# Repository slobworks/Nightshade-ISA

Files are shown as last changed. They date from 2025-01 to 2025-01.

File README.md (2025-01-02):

NIGHTSHADE v0.8c2 - Public Domain Cirrus Logic CL-GD542x Based ISA VGA Card

As it says on the package. This card supports a maximum memory size of 1MB or 2MB, depending on the chip you use, using traditional multiple-CAS FPM 256Kx16 SOJ memory. 70ns or faster is recommended.
Created using KiCAD 8.0.
front
back
Features:
- Four layer PCB with generous stitching vias for maximum possible signal integrity
- Optional dedicated regulator for analog DAC power for further improved picture quality
- Supports 1MB of memory with CL-GD5424, or 2MB with CL-GD5426/5428/5429
- Compatible with the N-well variants of the CL-GD542x, including the CL-GD5424, GD5426, GD5428 and GD5429
- Uses 29C010-compatible flash memory for reduced cost; has options to select one of four 32K banks within the large 128K flash memory if you wish to try multiple video BIOSes
- Features my own hand-drawn artwork on back of board

Release History:
- 0.8a: Fixed VESA Feature Connector pinout, now conforms to Cirrus datasheet
- 0.8b: Resolved a number of issues related to VGA output quality (no more wavy interference onscreen!), and reduced the parts count a bit. Fewer parts means less $$ spent, and less breathing of solder fumes.
- 0.8b2: Changed LM334SM to the _much_ cheaper LM334M.
- 0.8c: Pretty heavy tweak-up of both layout, ground pours, and placement of 75 ohm termination resistors following feedback from TmEE, Jorge and others. Thanks everyone who spoke up to help.
Also re-added DPAK LF50 regulator for the RAMDAC, and yes, it is optional if you want to pinch pennies on the dollar - just remember to only populate R22 if you're **not** using a regulator. If you're installing the regulator, leave R22 **OPEN**.
- 0.8c1: Changed ROM footprint to an SMD PLCC-32 socket, and had to re-space stuff around it to make it fit. This looks like it ought to work: https://www.digikey.com/en/products/detail/amphenol-cs-fci/69802-132LF/2023294
- 0.8c2: Moved the LDO and related junk to the front of the board to help minimize the potential for damage. Hopefully things don't get too hot, where it is.

Other people's stuff I've used:
- PLCC-32 footprint from KiCAD (SchrodingersGat ?): https://github.com/KiCad/Housings_LCC.pretty/blob/master/PLCC-32_SMD-Socket.kicad_mod

Released into the Public Domain. Use whatever license floats your boat on your own edits.

As you can see I'm a bit of a neophyte when it comes to this GitHub stuff.
Expect this to change as I become more familiar with the platform.

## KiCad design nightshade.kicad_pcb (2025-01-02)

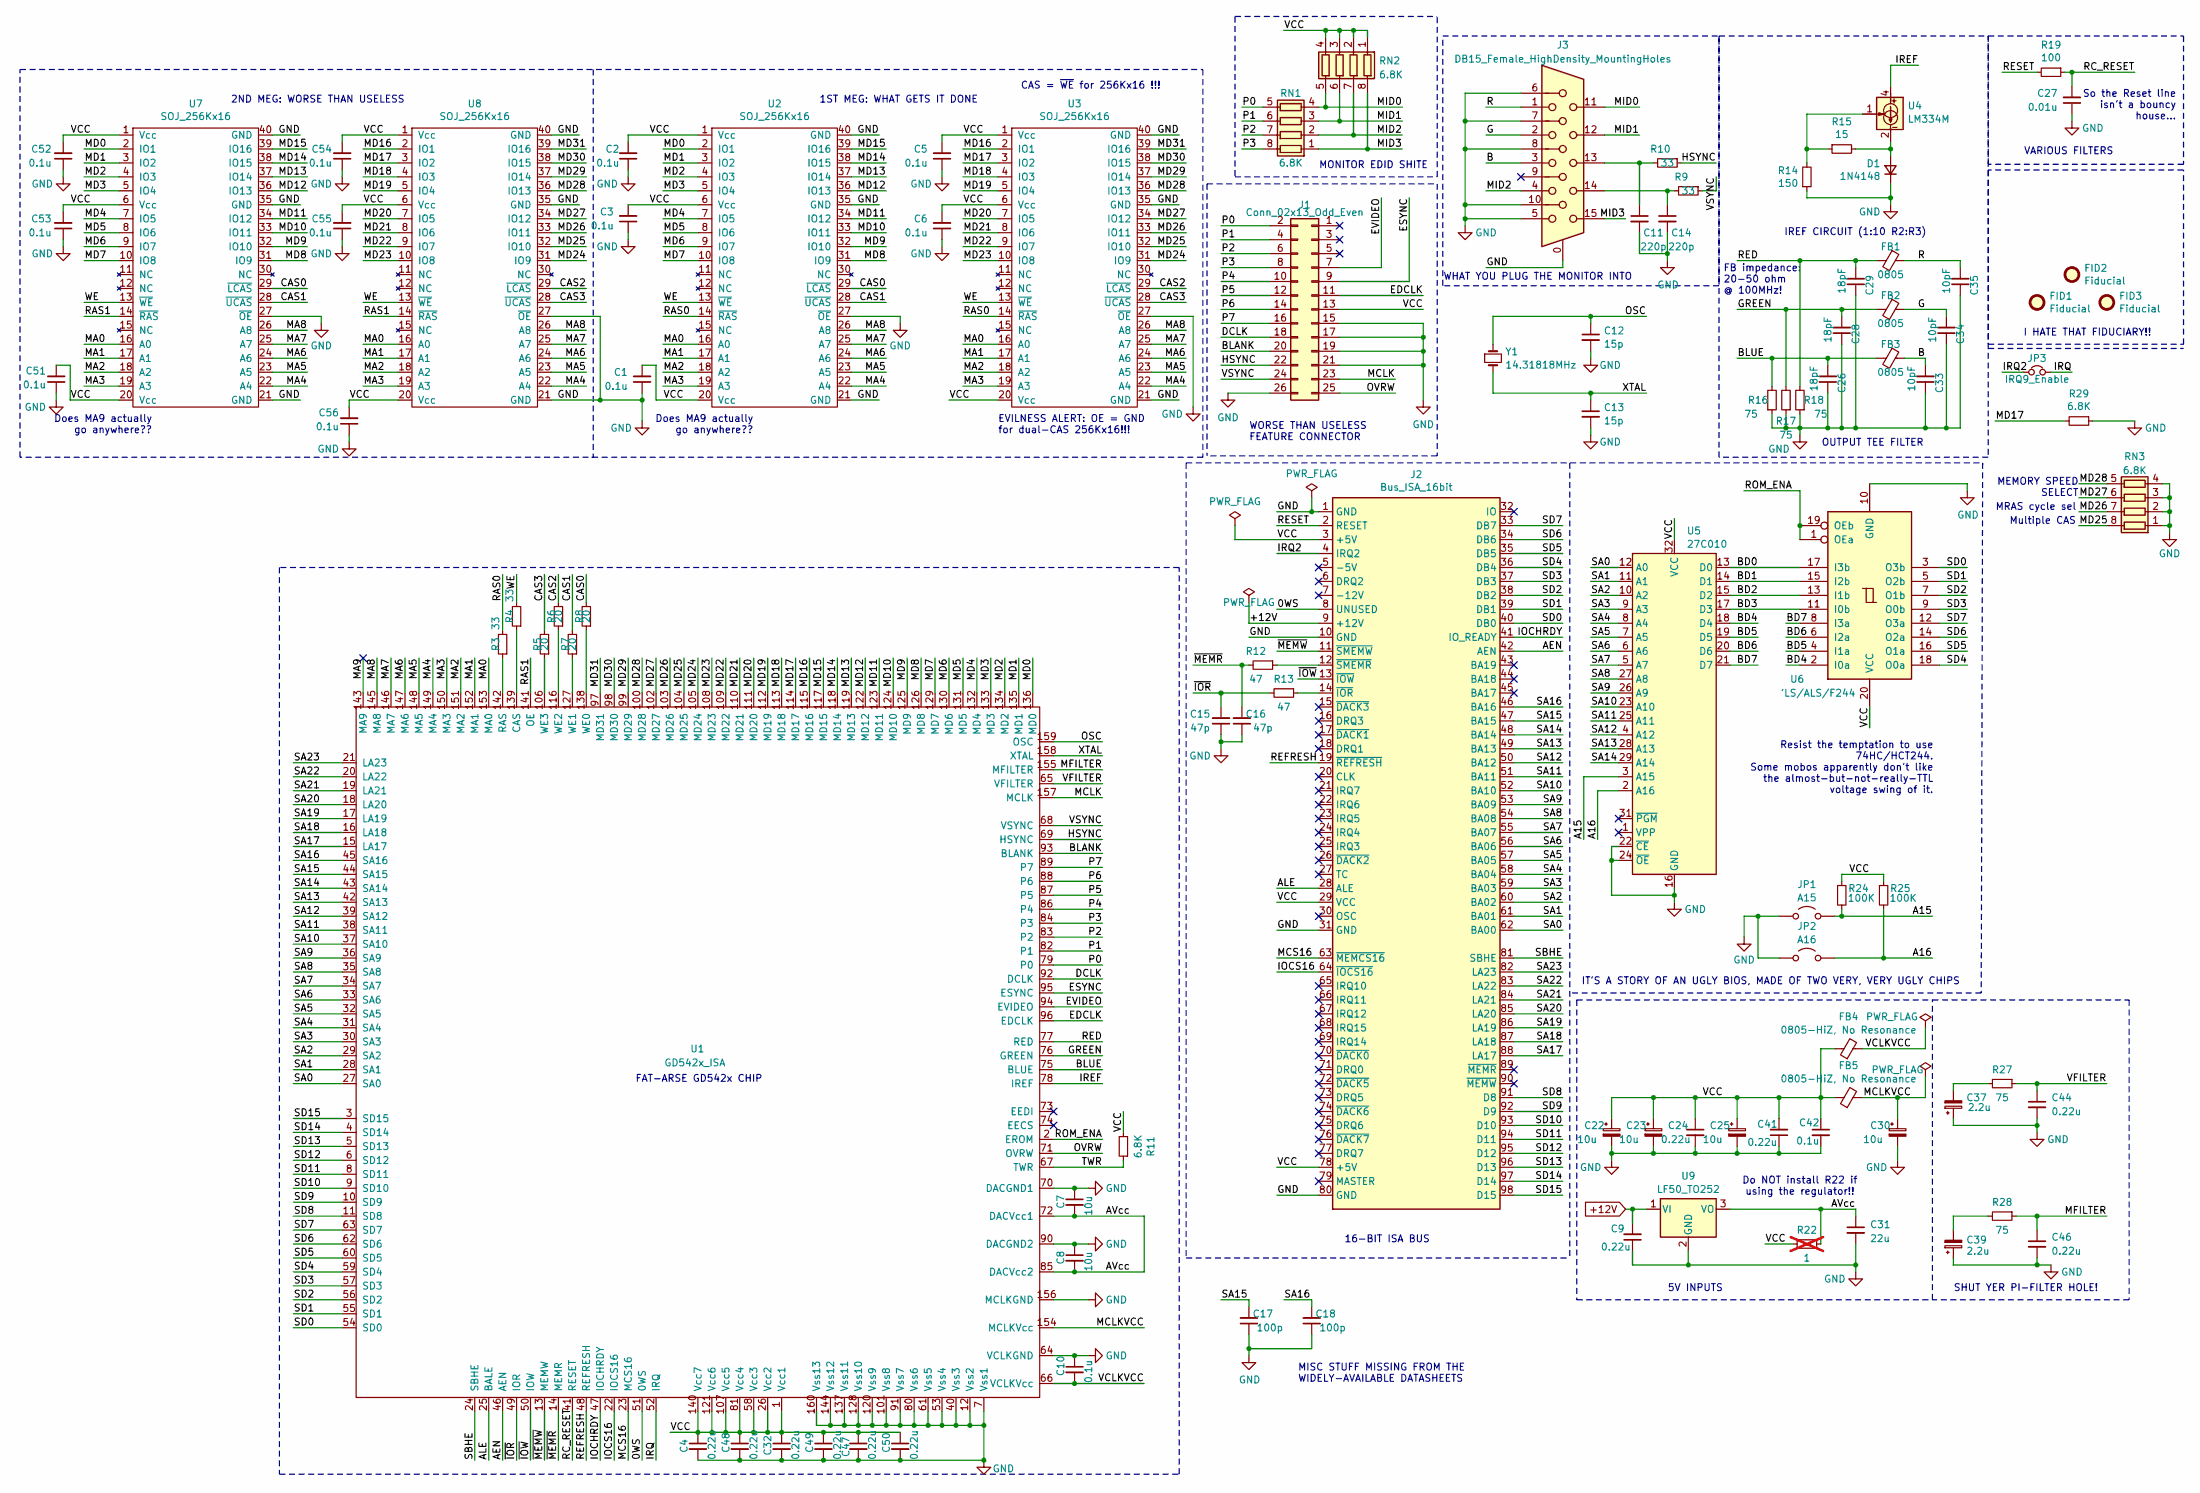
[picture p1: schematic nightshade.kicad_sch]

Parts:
C1, C2, C3, C5, C6, C10, C42, C51, C52, C53, C54, C55, C56: 0.1u; C_0805_2012Metric
C4, C9, C24, C32, C41, C44, C46, C47, C48, C49, C50: 0.22u; C_0805_2012Metric
C7, C8, C22, C23, C25, C30: 10u; C_1206_3216Metric
C11, C14: 220p; C_0805_2012Metric
C12, C13: 15p; C_0805_2012Metric
C15, C16: 47p; C_0805_2012Metric
C17, C18: 100p; C_0805_2012Metric
C26, C28, C29: 18pF; C_0805_2012Metric
C27: 0.01u; C_0805_2012Metric
C31: 22u; C_Elec_4x5.8
C33, C34, C35: 10pF; C_0805_2012Metric
C37, C39: 2.2u; C_0805_2012Metric
D1: 1N4148; D_SOD-323_HandSoldering
FB1, FB2, FB3: 0805; L_0805_2012Metric
FB4, FB5: 0805-HiZ, No Resonance; L_0805_2012Metric
FID1, FID2, FID3: Fiducial; Fiducial_1mm_Mask2mm
J1: Conn_02x13_Odd_Even; PinHeader_2x13_P2.54mm_Vertical
J2: Bus_ISA_16bit; BUS_AT
J3: DB15_Female_HighDensity_MountingHoles; DSUB-15-HD
JP1: A15; PinHeader_1x02_P1.27mm_Vertical
JP2: A16; PinHeader_1x02_P1.27mm_Vertical
JP3: IRQ9_Enable; PinHeader_1x02_P2.54mm_Vertical
R3, R4, R9, R10: 33; R_0805_2012Metric
R5, R6, R7, R8: 20; R_0805_2012Metric
R11: 6.8K; R_0603_1608Metric
R12, R13: 47; R_0805_2012Metric
R14: 150; R_0805_2012Metric
R15: 15; R_0805_2012Metric
R16, R17, R18, R27, R28: 75; R_0805_2012Metric
R19: 100; R_0805_2012Metric
R22: 1; R_0805_2012Metric; not fitted
R24, R25: 100K; R_0603_1608Metric
R29: 6.8K; R_0805_2012Metric
RN1, RN2, RN3: 6.8K; R_Array_Convex_4x0603
U1: GD542x_ISA; PQFP-160_28x28mm_P0.65mm
U2, U3, U7, U8: SOJ_256Kx16; SOJ-40_10.16x26.44mm_P1.27mm
U4: LM334M; SOIC-8_3.9x4.9mm_P1.27mm
U5: 27C010; PLCC-32_SMD-Socket
U6: 'LS/ALS/F244; SOIC-20W_7.5x12.8mm_P1.27mm
U9: LF50_TO252; TO-252-2
Y1: 14.31818MHz; Crystal_SMD_5032-2Pin_5.0x3.2mm_HandSoldering

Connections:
+12V: C9.2, J2.9 (+12V), U9.1 (VI)
/0WS: J2.8 (UNUSED), U1.51 (0WS)
/A15: JP1.2 (B), R24.2, U5.3 (A15)
/A16: JP2.2 (B), R25.2, U5.2 (A16)
/AEN: J2.42 (AEN), U1.46 (AEN)
/ALE: J2.28 (ALE), U1.25 (BALE)
/AVcc: C7.2, C8.2, C31.1, R22.1, U1.72 (DACVcc1), U1.85 (DACVcc2), U9.3 (VO)
/B: C33.2, FB3.1, J3.3
/BD0: U5.13 (D0), U6.17 (I3b)
/BD1: U5.14 (D1), U6.15 (I2b)
/BD2: U5.15 (D2), U6.13 (I1b)
/BD3: U5.17 (D3), U6.11 (I0b)
/BD4: U5.18 (D4), U6.2 (I0a)
/BD5: U5.19 (D5), U6.4 (I1a)
/BD6: U5.20 (D6), U6.6 (I2a)
/BD7: U5.21 (D7), U6.8 (I3a)
/BLANK: J1.20, U1.93 (BLANK)
/BLUE: C26.2, FB3.2, R16.2, U1.75 (BLUE)
/CAS0: R8.2, U2.29 (~LCAS), U7.29 (~LCAS)
/CAS1: R7.2, U2.28 (~UCAS), U7.28 (~UCAS)
/CAS2: R6.2, U3.29 (~LCAS), U8.29 (~LCAS)
/CAS3: R5.2, U3.28 (~UCAS), U8.28 (~UCAS)
/DCLK: J1.18, U1.92 (DCLK)
/EDCLK: J1.11, U1.96 (EDCLK)
/ESYNC: J1.9, U1.95 (ESYNC)
/EVIDEO: J1.7, U1.94 (EVIDEO)
/G: C34.2, FB2.1, J3.2
/GREEN: C28.2, FB2.2, R17.2, U1.76 (GREEN)
/HSYNC: J1.22, R10.1, U1.69 (HSYNC)
/IOCHRDY: J2.41 (IO_READY), U1.47 (IOCHRDY)
/IOCS16: J2.64 (~IOCS16), U1.22 (IOCS16)
/IREF: U1.78 (IREF), U4.4
/IRQ: JP3.2, U1.52 (IRQ)
/IRQ2: J2.4 (IRQ2), JP3.1
/MA0: U1.153 (MA0), U2.16 (A0), U3.16 (A0), U7.16 (A0), U8.16 (A0)
/MA1: U1.152 (MA1), U2.17 (A1), U3.17 (A1), U7.17 (A1), U8.17 (A1)
/MA2: U1.151 (MA2), U2.18 (A2), U3.18 (A2), U7.18 (A2), U8.18 (A2)
/MA3: U1.150 (MA3), U2.19 (A3), U3.19 (A3), U7.19 (A3), U8.19 (A3)
/MA4: U1.149 (MA4), U2.22 (A4), U3.22 (A4), U7.22 (A4), U8.22 (A4)
/MA5: U1.148 (MA5), U2.23 (A5), U3.23 (A5), U7.23 (A5), U8.23 (A5)
/MA6: U1.147 (MA6), U2.24 (A6), U3.24 (A6), U7.24 (A6), U8.24 (A6)
/MA7: U1.146 (MA7), U2.25 (A7), U3.25 (A7), U7.25 (A7), U8.25 (A7)
/MA8: U1.145 (MA8), U2.26 (A8), U3.26 (A8), U7.26 (A8), U8.26 (A8)
/MA9: U1.143 (MA9)
/MCLK: J1.23, U1.157 (MCLK)
/MCLKVCC: C30.1, FB5.2, U1.154 (MCLKVcc)
/MCS16: J2.63 (~MEMCS16), U1.23 (MCS16)
/MD0: U1.136 (MD0), U2.2 (IO1), U7.2 (IO1)
/MD1: U1.135 (MD1), U2.3 (IO2), U7.3 (IO2)
/MD2: U1.134 (MD2), U2.4 (IO3), U7.4 (IO3)
/MD3: U1.133 (MD3), U2.5 (IO4), U7.5 (IO4)
/MD4: U1.132 (MD4), U2.7 (IO5), U7.7 (IO5)
/MD5: U1.131 (MD5), U2.8 (IO6), U7.8 (IO6)
/MD6: U1.130 (MD6), U2.9 (IO7), U7.9 (IO7)
/MD7: U1.129 (MD7), U2.10 (IO8), U7.10 (IO8)
/MD8: U1.126 (MD8), U2.31 (IO9), U7.31 (IO9)
/MD9: U1.125 (MD9), U2.32 (IO10), U7.32 (IO10)
/MD10: U1.124 (MD10), U2.33 (IO11), U7.33 (IO11)
/MD11: U1.123 (MD11), U2.34 (IO12), U7.34 (IO12)
/MD12: U1.122 (MD12), U2.36 (IO13), U7.36 (IO13)
/MD13: U1.119 (MD13), U2.37 (IO14), U7.37 (IO14)
/MD14: U1.118 (MD14), U2.38 (IO15), U7.38 (IO15)
/MD15: U1.117 (MD15), U2.39 (IO16), U7.39 (IO16)
/MD16: U1.115 (MD16), U3.2 (IO1), U8.2 (IO1)
/MD17: R29.2, U1.114 (MD17), U3.3 (IO2), U8.3 (IO2)
/MD18: U1.113 (MD18), U3.4 (IO3), U8.4 (IO3)
/MD19: U1.112 (MD19), U3.5 (IO4), U8.5 (IO4)
/MD20: U1.111 (MD20), U3.7 (IO5), U8.7 (IO5)
/MD21: U1.110 (MD21), U3.8 (IO6), U8.8 (IO6)
/MD22: U1.109 (MD22), U3.9 (IO7), U8.9 (IO7)
/MD23: U1.108 (MD23), U3.10 (IO8), U8.10 (IO8)
/MD24: U1.105 (MD24), U3.31 (IO9), U8.31 (IO9)
/MD25: RN3.8 (R1.2), U1.104 (MD25), U3.32 (IO10), U8.32 (IO10)
/MD26: RN3.7 (R2.2), U1.103 (MD26), U3.33 (IO11), U8.33 (IO11)
/MD27: RN3.6 (R3.2), U1.102 (MD27), U3.34 (IO12), U8.34 (IO12)
/MD28: RN3.5 (R4.2), U1.100 (MD28), U3.36 (IO13), U8.36 (IO13)
/MD29: U1.99 (MD29), U3.37 (IO14), U8.37 (IO14)
/MD30: U1.98 (MD30), U3.38 (IO15), U8.38 (IO15)
/MD31: U1.97 (MD31), U3.39 (IO16), U8.39 (IO16)
/MFILTER: C46.1, R28.1, U1.155 (MFILTER)
/MID0: J3.11, RN1.4 (R4.1), RN2.5 (R4.2)
/MID1: J3.12, RN1.3 (R3.1), RN2.6 (R3.2)
/MID2: J3.4, RN1.2 (R2.1), RN2.7 (R2.2)
/MID3: J3.15, RN1.1 (R1.1), RN2.8 (R1.2)
/OSC: C12.1, U1.159 (OSC), Y1.1
/OVRW: J1.25, U1.71 (OVRW)
/P0: J1.2, RN1.5 (R4.2), U1.79 (P0)
/P1: J1.4, RN1.6 (R3.2), U1.82 (P1)
/P2: J1.6, RN1.7 (R2.2), U1.83 (P2)
/P3: J1.8, RN1.8 (R1.2), U1.84 (P3)
/P4: J1.10, U1.86 (P4)
/P5: J1.12, U1.87 (P5)
/P6: J1.14, U1.88 (P6)
/P7: J1.16, U1.89 (P7)
/R: C35.2, FB1.1, J3.1
/RAS0: R3.2, U2.14 (~RAS), U3.14 (~RAS)
/RAS1: U1.141 (OE), U7.14 (~RAS), U8.14 (~RAS)
/RC_RESET: C27.2, R19.1, U1.41 (RESET)
/RED: C29.2, FB1.2, R18.2, U1.77 (RED)
/REFRESH: J2.19 (~REFRESH), U1.48 (REFRESH)
/RESET: J2.2 (RESET), R19.2
/ROM_ENA: U1.2 (EROM), U6.1 (OEa), U6.19 (OEb)
/SA0: J2.62 (BA00), U1.27 (SA0), U5.12 (A0)
/SA1: J2.61 (BA01), U1.28 (SA1), U5.11 (A1)
/SA2: J2.60 (BA02), U1.29 (SA2), U5.10 (A2)
/SA3: J2.59 (BA03), U1.30 (SA3), U5.9 (A3)
/SA4: J2.58 (BA04), U1.31 (SA4), U5.8 (A4)
/SA5: J2.57 (BA05), U1.32 (SA5), U5.7 (A5)
/SA6: J2.56 (BA06), U1.33 (SA6), U5.6 (A6)
/SA7: J2.55 (BA07), U1.34 (SA7), U5.5 (A7)
/SA8: J2.54 (BA08), U1.35 (SA8), U5.27 (A8)
/SA9: J2.53 (BA09), U1.36 (SA9), U5.26 (A9)
/SA10: J2.52 (BA10), U1.37 (SA10), U5.23 (A10)
/SA11: J2.51 (BA11), U1.38 (SA11), U5.25 (A11)
/SA12: J2.50 (BA12), U1.39 (SA12), U5.4 (A12)
/SA13: J2.49 (BA13), U1.42 (SA13), U5.28 (A13)
/SA14: J2.48 (BA14), U1.43 (SA14), U5.29 (A14)
/SA15: C17.2, J2.47 (BA15), U1.44 (SA15)
/SA16: C18.2, J2.46 (BA16), U1.45 (SA16)
/SA17: J2.88 (LA17), U1.15 (LA17)
/SA18: J2.87 (LA18), U1.16 (LA18)
/SA19: J2.86 (LA19), U1.17 (LA19)
/SA20: J2.85 (LA20), U1.18 (LA20)
/SA21: J2.84 (LA21), U1.19 (LA21)
/SA22: J2.83 (LA22), U1.20 (LA22)
/SA23: J2.82 (LA23), U1.21 (LA23)
/SBHE: J2.81 (SBHE), U1.24 (SBHE)
/SD0: J2.40 (DB0), U1.54 (SD0), U6.3 (O3b)
/SD1: J2.39 (DB1), U1.55 (SD1), U6.5 (O2b)
/SD2: J2.38 (DB2), U1.56 (SD2), U6.7 (O1b)
/SD3: J2.37 (DB3), U1.57 (SD3), U6.9 (O0b)
/SD4: J2.36 (DB4), U1.59 (SD4), U6.18 (O0a)
/SD5: J2.35 (DB5), U1.60 (SD5), U6.16 (O1a)
/SD6: J2.34 (DB6), U1.62 (SD6), U6.14 (O2a)
/SD7: J2.33 (DB7), U1.63 (SD7), U6.12 (O3a)
/SD8: J2.91 (D8), U1.11 (SD8)
/SD9: J2.92 (D9), U1.10 (SD9)
/SD10: J2.93 (D10), U1.9 (SD10)
/SD11: J2.94 (D11), U1.8 (SD11)
/SD12: J2.95 (D12), U1.6 (SD12)
/SD13: J2.96 (D13), U1.5 (SD13)
/SD14: J2.97 (D14), U1.4 (SD14)
/SD15: J2.98 (D15), U1.3 (SD15)
/TWR: R11.1, U1.67 (TWR)
/VCC: C1.2, C2.2, C3.2, C4.1, C5.2, C6.2, C22.1, C23.1, C24.1, C25.1, C32.1, C41.2, C42.1, C47.1, C48.1, C49.1, C50.1, C51.2, C52.2, C53.2, C54.2, C55.2, C56.2, FB4.1, FB5.1, J1.13, J2.3 (+5V), J2.29 (VCC), J2.78 (+5V), R11.2, R22.2, R24.1, R25.1, RN2.1 (R1.1), RN2.2 (R2.1), RN2.3 (R3.1), RN2.4 (R4.1), U1.1 (Vcc1), U1.26 (Vcc2), U1.58 (Vcc3), U1.81 (Vcc4), U1.107 (Vcc5), U1.121 (Vcc6), U1.140 (Vcc7), U2.1 (Vcc), U2.6 (Vcc), U2.20 (Vcc), U3.1 (Vcc), U3.6 (Vcc), U3.20 (Vcc), U5.32 (VCC), U6.20 (VCC), U7.1 (Vcc), U7.6 (Vcc), U7.20 (Vcc), U8.1 (Vcc), U8.6 (Vcc), U8.20 (Vcc)
/VCLKVCC: C10.2, FB4.2, U1.66 (VCLKVcc)
/VFILTER: C44.1, R27.1, U1.65 (VFILTER)
/VSYNC: J1.24, R9.1, U1.68 (VSYNC)
/WE: R4.2, U2.13 (~WE), U3.13 (~WE), U7.13 (~WE), U8.13 (~WE)
/XTAL: C13.1, U1.158 (XTAL), Y1.2
/~IOR: C15.2, R13.2, U1.49 (IOR)
/~IOW: J2.13 (~IOW), U1.50 (IOW)
/~MEMR: C16.2, R12.2, U1.14 (MEMR)
/~MEMW: J2.11 (~SMEMW), U1.13 (MEMW)
GND: C1.1, C2.1, C3.1, C4.2, C5.1, C6.1, C7.1, C8.1, C9.1, C10.1, C11.2, C12.2, C13.2, C14.2, C15.1, C16.1, C17.1, C18.1, C22.2, C23.2, C24.2, C25.2, C26.1, C27.1, C28.1, C29.1, C30.2, C31.2, C32.2, C33.1, C34.1, C35.1, C37.1, C39.1, C41.1, C42.2, C44.2, C46.2, C47.2, C48.2, C49.2, C50.2, C51.1, C52.1, C53.1, C54.1, C55.1, C56.1, D1.1 (K), J1.15, J1.17, J1.19, J1.21, J1.26, J2.1 (GND), J2.10 (GND), J2.31 (GND), J2.80 (GND), J3.0, J3.5, J3.6, J3.7, J3.8, J3.10, JP1.1 (A), JP2.1 (A), R14.1, R16.1, R17.1, R18.1, R29.1, RN3.1 (R1.1), RN3.2 (R2.1), RN3.3 (R3.1), RN3.4 (R4.1), U1.7 (Vss1), U1.12 (Vss2), U1.40 (Vss3), U1.53 (Vss4), U1.61 (Vss5), U1.64 (VCLKGND), U1.70 (DACGND1), U1.80 (Vss6), U1.90 (DACGND2), U1.91 (Vss7), U1.101 (Vss8), U1.120 (Vss9), U1.128 (Vss10), U1.137 (Vss11), U1.144 (Vss12), U1.156 (MCLKGND), U1.160 (Vss13), U2.21 (GND), U2.27 (~OE), U2.35 (GND), U2.40 (GND), U3.21 (GND), U3.27 (~OE), U3.35 (GND), U3.40 (GND), U5.16 (GND), U5.22 (~CE), U5.24 (~OE), U6.10 (GND), U7.21 (GND), U7.27 (~OE), U7.35 (GND), U7.40 (GND), U8.21 (GND), U8.27 (~OE), U8.35 (GND), U8.40 (GND), U9.2 (GND)
unnamed: C11.1, J3.13, R10.2
unnamed: C14.1, J3.14, R9.2
unnamed: C37.2, R27.2
unnamed: C39.2, R28.2
unnamed: D1.2 (A), R15.2, U4.2, U4.3, U4.6, U4.7
unnamed: J2.14 (~IOR), R13.1
unnamed: J2.12 (~SMEMR), R12.1
unnamed: R14.2, R15.1, U4.1
unnamed: R4.1, U1.139 (CAS)
unnamed: R3.1, U1.142 (RAS)
unnamed: R8.1, U1.138 (WE0)
unnamed: R7.1, U1.127 (WE1)
unnamed: R6.1, U1.116 (WE2)
unnamed: R5.1, U1.106 (WE3)

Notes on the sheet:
Resist the temptation to use 74HC/HCT244. Some mobos apparently don't like the almost-but-not-really-TTL voltage swing of it.
16-BIT ISA BUS
IT'S A STORY OF AN UGLY BIOS, MADE OF TWO VERY, VERY UGLY CHIPS
Multiple CAS
Does MA9 actually go anywhere??
So the Reset line isn't a bouncy house...
2ND MEG: WORSE THAN USELESS
VARIOUS FILTERS
SHUT YER PI-FILTER HOLE!
MONITOR EDID SHITE
IREF CIRCUIT (1:10 R2:R3)
CAS = ~{WE} for 256Kx16 !!!
Do NOT install R22 if using the regulator!!
FAT-ARSE GD542x CHIP
1ST MEG: WHAT GETS IT DONE
MISC STUFF MISSING FROM THE WIDELY-AVAILABLE DATASHEETS
MEMORY SPEED SELECT
5V INPUTS
WHAT YOU PLUG THE MONITOR INTO
FB impedance: 20-50 ohm @ 100MHz!
WORSE THAN USELESS FEATURE CONNECTOR
I HATE THAT FIDUCIARY!!
MRAS cycle sel
EVILNESS ALERT: OE = GND for dual-CAS 256Kx16!!!
OUTPUT TEE FILTER

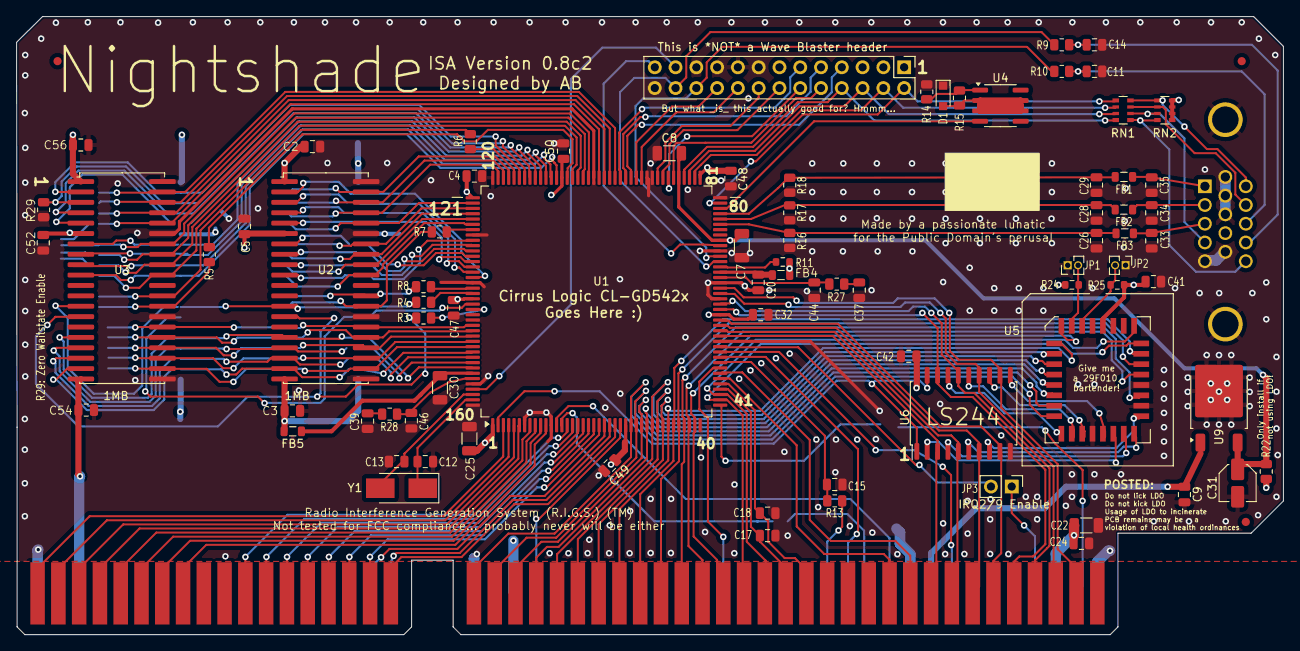
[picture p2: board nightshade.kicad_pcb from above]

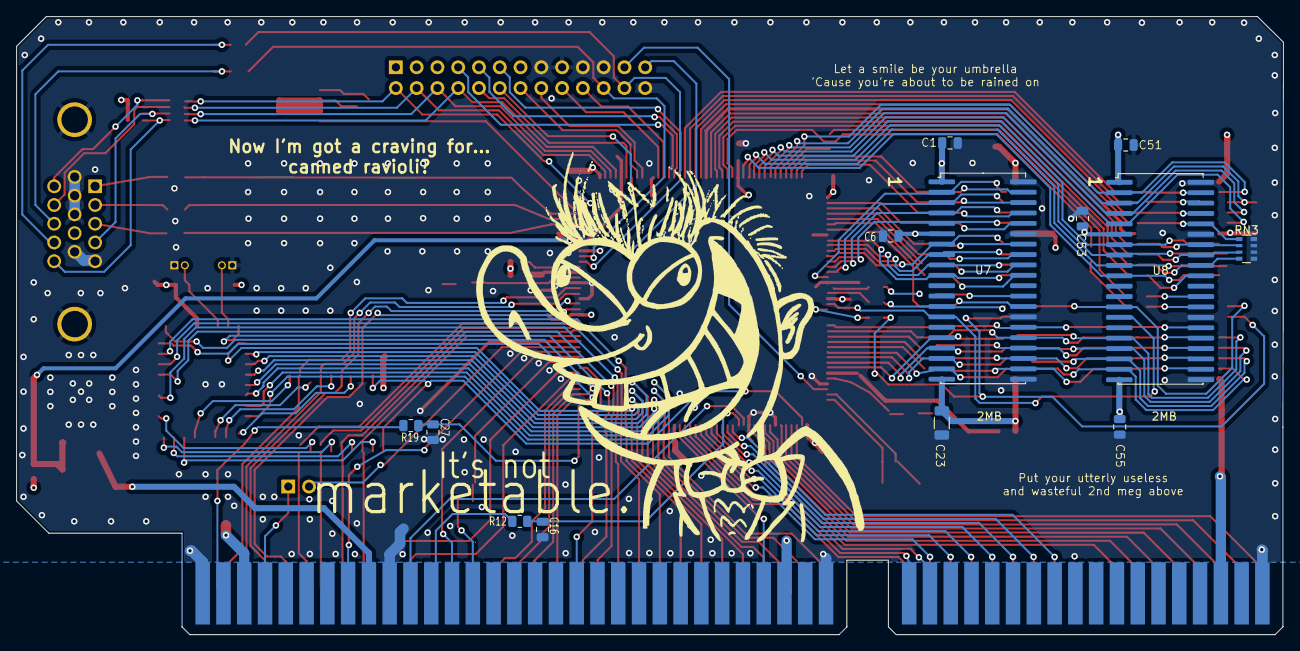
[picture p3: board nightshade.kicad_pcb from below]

Board: 4 copper layers, 154.9 x 75.5 mm, 100 parts (14 on the bottom side), 168 nets.

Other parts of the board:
G1: LOGO; ugly

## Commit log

2024-12-14 Add files via upload
    Updated to Version 0.8
    [nightshade-B_Cu.gbr, nightshade-B_Mask.gbr, nightshade-B_Paste.gbr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]
2024-12-24 Update README.md
    Whoopsadoodle, realized that the VFC connector is busted
2024-12-24 Add files via upload
    Uploaded version 0.8a, which fixes among other things the VFC connector pinout.
    [nightshade-B_Cu.gbr, nightshade-B_Mask.gbr, nightshade-B_Paste.gbr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]
2024-12-24 Add files via upload
    Added CSV BOM file
2024-12-24 Add files via upload
    quick fixes
    [nightshade-B_Cu.gbr, nightshade-B_Mask.gbr, nightshade-B_Paste.gbr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]
2024-12-24 Add files via upload
    0.8a is finalized! Merry Christmas!
    [nightshade-B_Cu.gbr, nightshade-B_Mask.gbr, nightshade-B_Paste.gbr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]
2024-12-26 Add files via upload
    Updated to version 0.8b. Merry Christmas!
    [nightshade-B_Cu.gbr, nightshade-B_Mask.gbr, nightshade-B_Paste.gbr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]
2024-12-29 Add files via upload
    Updated to 0.8b2
    [nightshade-B_Cu.gbr, nightshade-B_Mask.gbr, nightshade-B_Paste.gbr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]
2025-01-02 Add files via upload
    Updated to version 0.8c.
    [nightshade-B_Cu.gbr, nightshade-B_Mask.gbr, nightshade-B_Paste.gbr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]
2025-01-02 Add files via upload
    updated to 0.8c1.
    [nightshade-B_Cu.gbr, nightshade-B_Mask.gbr, nightshade-B_Paste.gbr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]
2025-01-02 Add files via upload
    Updated to Version 0.8c2.
    [nightshade-B_Cu.gbr, nightshade-B_Mask.gbr, nightshade-B_Paste.gbr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]

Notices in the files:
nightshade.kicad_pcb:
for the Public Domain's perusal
